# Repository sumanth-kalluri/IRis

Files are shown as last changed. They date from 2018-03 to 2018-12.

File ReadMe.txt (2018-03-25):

Instructions To Run

Dependencies :
tiny_IRremote (For IR Communication on ATtiny85)
IRremote (For IR Communication on Arduino Uno)

The code in "Slave Side" Folder should be burnt to ATtiny85 (with 8Mhz Clock Rate)

The code in "Master Side/IR Interface (Arduino)" Folder should be burnt to Arduino Uno

The folder "Master Side/Hub (Raspberry Pi)" should be copied to Raspberry Pi.

"Master Side/Hub (Raspberry Pi)/Operation Files" contains the python scripts which drive IRis on Raspberry Pi

"Master Side/Hub (Raspberry Pi)/Responses" stores the responses given by students

"Master Side/Hub (Raspberry Pi)/Question Sets" stores the question sets for quizzes

"Master Side/Hub (Raspberry Pi)/Operation Files/serverSync.py" handles the server synchronization and should be added to startup files.

"Master Side/Hub (Raspberry Pi)/IRis-Launcher" invokes the python script in the "Master Side/Hub (Raspberry Pi)/Operation Files" Folder

Hardware Designs can be found in the schematics folder and in the Arduino codes

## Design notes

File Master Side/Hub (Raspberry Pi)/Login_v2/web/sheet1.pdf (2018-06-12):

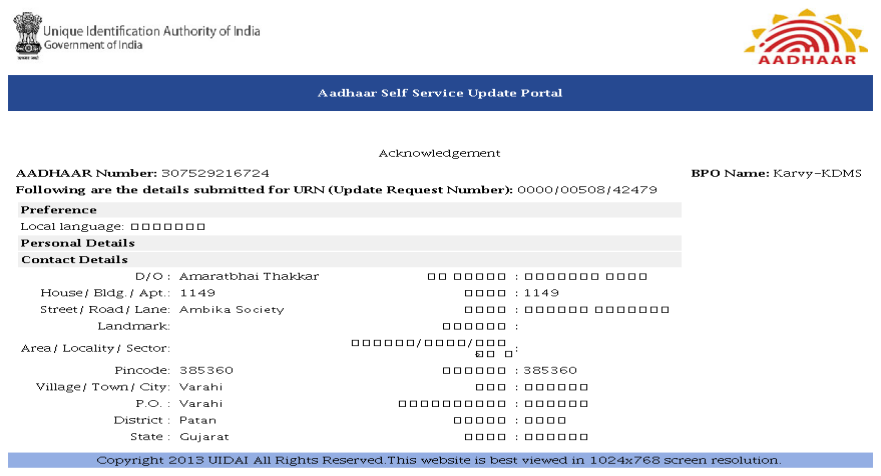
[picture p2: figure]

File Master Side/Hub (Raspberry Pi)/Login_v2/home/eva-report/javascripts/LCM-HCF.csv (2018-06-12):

Roll No. | q1 | ans1 | q2 | ans2 | q3 | ans3 | q4 | ans4 | q5 | ans5 | q6 | ans6 | q7 | ans7 | q8 | ans8 | q9 | ans9 | q10 | ans10 | q11 | ans11 | q12 | ans12 | q13 | ans13 | q14 | ans14 | q15 | ans15
1 | D | 0 | A | MEL420 | C | MEL420 | D | 0 | B | MEL4173 | C | MEL417111 | C | MEL417111 | D | MEL421 | A | 0 | A | 0 | C | MEL420 | B | 0 | A | MEL420 | C | 0 | D | MEL4191
2 | D | 0 | A | MEL420 | C | MEL420 | D | 0 | B | MEL4173 | C | MEL417111 | C | MEL417111 | D | MEL421 | A | 0 | A | 0 | C | MEL420 | B | 0 | A | MEL420 | C | 0 | D | MEL4191
3 | D | 0 | A | MEL420 | C | MEL420 | D | 0 | B | MEL4173 | C | MEL417111 | C | MEL417111 | D | MEL421 | A | 0 | A | 0 | C | MEL420 | B | 0 | A | MEL420 | C | 0 | D | MEL4191
4 | D | 0 | A | MEL420 | C | MEL420 | D | 0 | B | MEL4173 | C | MEL417111 | C | MEL417111 | D | MEL421 | A | 0 | A | 0 | C | MEL420 | B | 0 | A | MEL420 | C | 0 | D | MEL4191
5 | D | 0 | x | x | C | MEL420 | D | 0 | x | x | C | MEL417111 | C | MEL417111 | D | MEL421 | A | 0 | A | 0 | C | MEL420 | B | 0 | x | x | C | 0 | D | MEL4191
6 | D | 0 | A | MEL420 | C | MEL420 | D | 0 | B | MEL4173 | C | MEL417111 | C | MEL417111 | D | MEL421 | A | 0 | A | 0 | C | MEL420 | B | 0 | A | MEL420 | C | 0 | D | MEL4191
7 | D | 0 | A | MEL420 | C | MEL420 | D | 0 | B | MEL4173 | C | MEL417111 | C | MEL417111 | D | MEL421 | A | 0 | A | 0 | C | MEL420 | B | 0 | A | MEL420 | C | 0 | D | MEL4191
8 | D | 0 | A | MEL420 | C | MEL420 | D | 0 | B | MEL4173 | C | MEL417111 | C | MEL417111 | D | MEL421 | A | 0 | A | 0 | C | MEL420 | B | 0 | A | MEL420 | C | 0 | D | MEL4191
9 | D | 0 | A | MEL420 | C | MEL420 | D | 0 | B | MEL4173 | C | MEL417111 | C | MEL417111 | D | MEL421 | A | 0 | A | 0 | C | MEL420 | B | 0 | A | MEL420 | C | 0 | D | MEL4191
10 | D | 0 | A | MEL420 | C | MEL420 | D | 0 | B | MEL4173 | C | MEL417111 | C | MEL417111 | D | MEL421 | A | 0 | A | 0 | C | MEL420 | B | 0 | A | MEL420 | C | 0 | D | MEL4191
11 | D | 0 | A | MEL420 | C | MEL420 | D | 0 | B | MEL4173 | C | MEL417111 | C | MEL417111 | D | MEL421 | A | 0 | A | 0 | C | MEL420 | B | 0 | A | MEL420 | C | 0 | D | MEL4191
12 | D | 0 | A | MEL420 | C | MEL420 | D | 0 | B | MEL4173 | C | MEL417111 | C | MEL417111 | D | MEL421 | A | 0 | A | 0 | C | MEL420 | B | 0 | A | MEL420 | C | 0 | D | MEL4191
13 | D | 0 | A | MEL420 | C | MEL420 | D | 0 | B | MEL4173 | C | MEL417111 | C | MEL417111 | D | MEL421 | A | 0 | A | 0 | C | MEL420 | B | 0 | A | MEL420 | C | 0 | D | MEL4191
14 | D | 0 | A | MEL420 | C | MEL420 | D | 0 | B | MEL4173 | C | MEL417111 | C | MEL417111 | D | MEL421 | A | 0 | A | 0 | C | MEL420 | B | 0 | A | MEL420 | C | 0 | D | MEL4191
15 | D | 0 | A | MEL420 | C | MEL420 | D | 0 | B | MEL4173 | C | MEL417111 | C | MEL417111 | D | MEL421 | A | 0 | A | 0 | C | MEL420 | B | 0 | A | MEL420 | C | 0 | D | MEL4191
16 | D | 0 | A | MEL420 | C | MEL420 | D | 0 | B | MEL4173 | C | MEL417111 | C | MEL417111 | D | MEL421 | A | 0 | A | 0 | C | MEL420 | B | 0 | A | MEL420 | C | 0 | D | MEL4191
17 | D | 0 | A | MEL420 | C | MEL420 | D | 0 | B | MEL4173 | C | MEL417111 | C | MEL417111 | D | MEL421 | A | 0 | A | 0 | C | MEL420 | B | 0 | A | MEL420 | C | 0 | D | MEL4191
18 | D | 0 | A | MEL420 | C | MEL420 | D | 0 | B | MEL4173 | C | MEL417111 | C | MEL417111 | D | MEL421 | A | 0 | A | 0 | C | MEL420 | B | 0 | A | MEL420 | C | 0 | D | MEL4191
19 | D | 0 | A | MEL420 | C | MEL420 | D | 0 | B | MEL4173 | C | MEL417111 | C | MEL417111 | D | MEL421 | A | 0 | A | 0 | C | MEL420 | B | 0 | A | MEL420 | C | 0 | D | MEL4191
20 | D | 0 | A | MEL420 | C | MEL420 | D | 0 | B | MEL4173 | C | MEL417111 | C | MEL417111 | D | MEL421 | A | 0 | A | 0 | C | MEL420 | B | 0 | A | MEL420 | C | 0 | D | MEL4191
21 | D | 0 | A | MEL420 | C | MEL420 | D | 0 | B | MEL4173 | C | MEL417111 | C | MEL417111 | D | MEL421 | A | 0 | A | 0 | C | MEL420 | B | 0 | A | MEL420 | C | 0 | D | MEL4191
22 | D | 0 | A | MEL420 | C | MEL420 | D | 0 | B | MEL4173 | C | MEL417111 | C | MEL417111 | D | MEL421 | A | 0 | A | 0 | C | MEL420 | B | 0 | A | MEL420 | C | 0 | D | MEL4191
23 | D | 0 | A | MEL420 | C | MEL420 | D | 0 | B | MEL4173 | C | MEL417111 | C | MEL417111 | D | MEL421 | A | 0 | A | 0 | C | MEL420 | B | 0 | A | MEL420 | C | 0 | D | MEL4191
24 | D | 0 | A | MEL420 | C | MEL420 | D | 0 | B | MEL4173 | C | MEL417111 | C | MEL417111 | D | MEL421 | A | 0 | A | 0 | C | MEL420 | B | 0 | A | MEL420 | C | 0 | D | MEL4191

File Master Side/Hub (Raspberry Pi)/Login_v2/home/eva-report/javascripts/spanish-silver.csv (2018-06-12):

year | situados_paid | silver_minted | was_american_revolution
1720 | 1226215 | 7874315 | 0
1721 | 1046440 | 9460730 | 0
1722 | 376311 | 8823927 | 0
1723 | 921332 | 8107343 | 0
1724 | 928764 | 7872819 | 0
1725 | 698335 | 7369815 | 0
1726 | 690360 | 8236645 | 0
1727 | 702108 | 8133081 | 0
1728 | 353345 | 9228544 | 0
1729 | 640906 | 8814968 | 0
1730 | 714051 | 9745871 | 0
1731 | 961858 | 8439871 | 0
1732 | 1063585 | 8726466 | 0
1733 | 1148936 | 10009796 | 0
1734 | 308749 | 8506554 | 0
1735 | 1063897 | 7922009 | 0
1736 | 880634 | 11016000 | 0
1737 | 1103957 | 8122133 | 0
1738 | 1083357 | 9490250 | 0
1739 | 524605 | 8550686 | 0
1740 | 1320670 | 9556040 | 0
1741 | 1948375 | 8644177 | 0
1742 | 672024 | 8177000 | 0
1743 | 1622300 | 8619000 | 0
1744 | 1349189 | 10285000 | 0
1745 | 1493178 | 10327500 | 0
1746 | 1457684 | 11509000 | 0
1747 | 1468279 | 12002000 | 0
1748 | 2402106 | 11628000 | 0
1749 | 2138665 | 11823500 | 0
1750 | 1614920 | 13209000 | 0
1751 | 848271 | 12631000 | 0
1752 | 918960 | 13625500 | 0
1753 | 2227312 | 11594000 | 0
1754 | 1775134 | 11594000 | 0
1755 | 2064520 | 12486500 | 0
1756 | 311502 | 12299500 | 0
1757 | 3687895 | 12529000 | 0
1758 | 2313552 | 12757591 | 0
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

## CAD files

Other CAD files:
Casing/IRis Slave Casing (AA Cell - Bottom Loading).dwg
Casing/IRis Slave Casing (CR2032 Cell).dwg
Casing/IRis Slave Casing (AA Cell - Side Loading).dwg

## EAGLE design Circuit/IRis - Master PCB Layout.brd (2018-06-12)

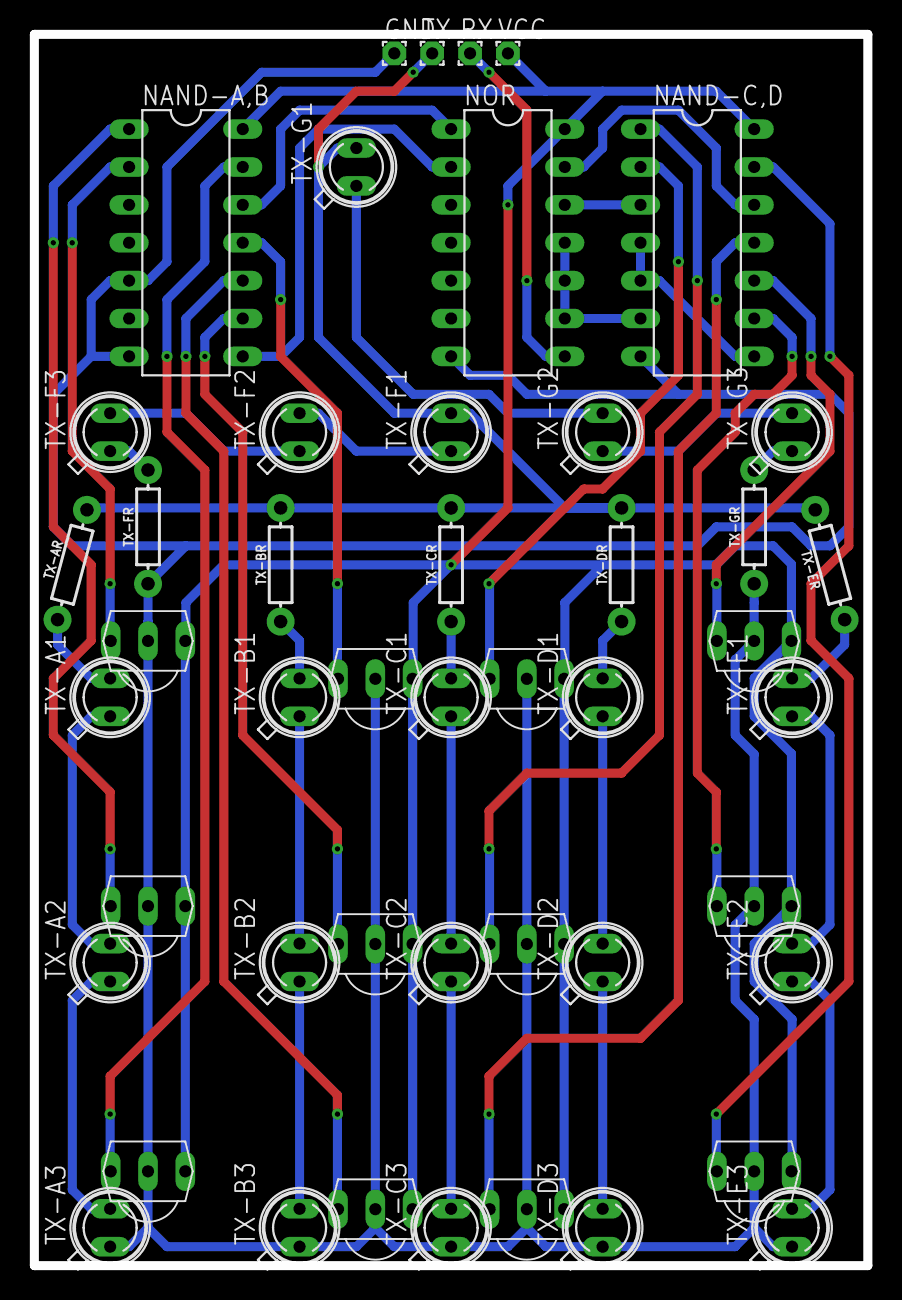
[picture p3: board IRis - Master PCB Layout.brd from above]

Board: 2 copper layers, 55.9 x 82.5 mm, 47 parts (0 on the bottom side), 43 nets.

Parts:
GND: GND; 1,6/0,8
NAND-A,B: 7410; DIL14
NAND-C,D: 7410; DIL14
NOR: 7427; DIL14
RX: RX; 1,6/0,8
RX-A1, RX-A2, RX-A3: VS1838B; TSOP18XX
RX-B1, RX-B2, RX-B3: VS1838B; TSOP18XX
RX-C1, RX-C2, RX-C3: VS1838B; TSOP18XX
RX-D1, RX-D2, RX-D3: TSOP18XX
TX: TX; 1,6/0,8
TX-A1: IR LED; SFH480
TX-A2, TX-A3: SFH480
TX-AR: AXIAL-0.3EZ
TX-B1, TX-B2, TX-B3: SFH480
TX-BR: AXIAL-0.3EZ
TX-C1, TX-C2, TX-C3: SFH480
TX-CR: AXIAL-0.3EZ
TX-D1, TX-D2, TX-D3: SFH480
TX-DR: AXIAL-0.3EZ
TX-E1, TX-E2, TX-E3: SFH480
TX-ER: AXIAL-0.3EZ
TX-F1, TX-F2, TX-F3: SFH480
TX-FR: AXIAL-0.3EZ
TX-G1, TX-G2, TX-G3: SFH480
TX-GR: AXIAL-0.3EZ
VCC: VCC; 1,6/0,8

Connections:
GND: GND.1, NAND-A,B.5, NAND-A,B.7, NAND-C,D.7, NOR.7, RX-A1.GND, RX-A2.GND, RX-A3.GND, RX-B1.GND, RX-B2.GND, RX-B3.GND, RX-C1.GND, RX-C2.GND, RX-C3.GND, RX-D1.GND, RX-D2.GND, RX-D3.GND, TX-A3.K, TX-B3.K, TX-C3.K, TX-D3.K, TX-E3.K, TX-FR.P$1, TX-GR.P$1
RX: NOR.8, RX.1
S$23: NAND-C,D.4, NAND-C,D.5, NAND-C,D.8
S$25: NAND-C,D.1, RX-C2.OUT
S$26: NAND-C,D.11, RX-C3.OUT
S$27: NAND-C,D.9, RX-D2.OUT
S$29: NAND-C,D.2, RX-C1.OUT
S$32: NAND-C,D.12, NOR.13
S$33: NAND-C,D.3, NOR.12
S$34: NAND-C,D.6, NOR.9, NOR.10, NOR.11
S$35: NAND-A,B.12, NOR.1
S$36: NAND-A,B.8, NOR.2
S$37: NAND-A,B.2, RX-A1.OUT
S$38: NAND-A,B.1, RX-A2.OUT
S$39: NAND-A,B.13, RX-A3.OUT
S$40: NAND-A,B.11, RX-B1.OUT
S$41: NAND-A,B.9, RX-B2.OUT
S$42: NAND-A,B.10, RX-B3.OUT
S$43: NAND-C,D.10, RX-D1.OUT
S$44: NAND-C,D.13, RX-D3.OUT
TX: TX.1, TX-AR.P$2, TX-BR.P$2, TX-CR.P$2, TX-DR.P$2, TX-ER.P$2, TX-F1.A, TX-G1.A
TX-A1,A2: TX-A1.K, TX-A2.A
TX-A2,A3: TX-A2.K, TX-A3.A
TX-AR,A1: TX-A1.A, TX-AR.P$1
TX-B1,B2: TX-B1.K, TX-B2.A
TX-B2,B3: TX-B2.K, TX-B3.A
TX-BR,B1: TX-B1.A, TX-BR.P$1
TX-C1,C2: TX-C1.K, TX-C2.A
TX-C2,C3: TX-C2.K, TX-C3.A
TX-CR,C1: TX-C1.A, TX-CR.P$1
TX-D1,D2: TX-D1.K, TX-D2.A
TX-D2,D3: TX-D2.K, TX-D3.A
TX-DR,D1: TX-D1.A, TX-DR.P$1
TX-E1,E2: TX-E1.K, TX-E2.A
TX-E2,E3: TX-E2.K, TX-E3.A
TX-ER,E1: TX-E1.A, TX-ER.P$1
TX-F1,F2: TX-F1.K, TX-F2.A
TX-F2,F3: TX-F2.K, TX-F3.A
TX-F3,FR: TX-F3.K, TX-FR.P$2
TX-G1,G2: TX-G1.K, TX-G2.A
TX-G2,G3: TX-G2.K, TX-G3.A
TX-G3,R: TX-G3.K, TX-GR.P$2
VCC: NAND-A,B.14, NAND-C,D.14, NOR.14, RX-A1.VCC, RX-A2.VCC, RX-A3.VCC, RX-B1.VCC, RX-B2.VCC, RX-B3.VCC, RX-C1.VCC, RX-C2.VCC, RX-C3.VCC, RX-D1.VCC, RX-D2.VCC, RX-D3.VCC, VCC.1

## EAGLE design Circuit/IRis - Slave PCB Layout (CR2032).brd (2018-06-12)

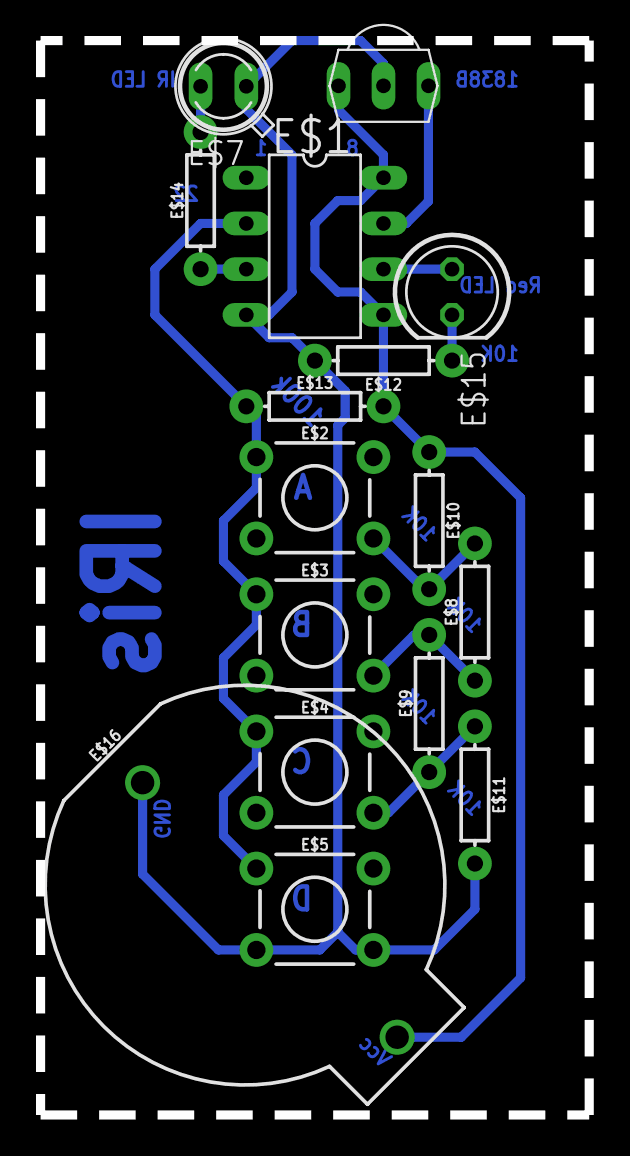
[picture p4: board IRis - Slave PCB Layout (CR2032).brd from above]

Board: 2 copper layers, 30.5 x 59.7 mm, 16 parts (0 on the bottom side), 11 nets.

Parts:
E$1: DIL8
E$2, E$3, E$4, E$5: TACTILE_SWITCH_PTH_6.0MM
E$6: TSOP18XX
E$7: SFH480
E$8, E$9, E$10, E$11, E$12, E$13, E$14: AXIAL-0.3
E$15: LED5MM
E$16: BATTCOM_20MM_PTH

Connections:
GND: E$1.4, E$5.3, E$5.4, E$6.GND, E$7.K, E$11.P$2, E$12.P$2, E$16.2
S$1: E$2.4, E$8.P$2, E$10.P$2
S$2: E$1.5, E$1.8, E$6.VCC, E$10.P$1, E$13.P$2, E$16.1
S$3: E$3.4, E$8.P$1, E$9.P$2
S$4: E$1.3, E$14.P$1
S$5: E$1.2, E$2.1, E$3.1, E$4.1, E$5.1, E$13.P$1
S$6: E$4.4, E$9.P$1, E$11.P$1
S$7: E$7.A, E$14.P$2
S$8: E$1.7, E$6.OUT
S$9: E$1.6, E$15.A
S$10: E$12.P$1, E$15.K

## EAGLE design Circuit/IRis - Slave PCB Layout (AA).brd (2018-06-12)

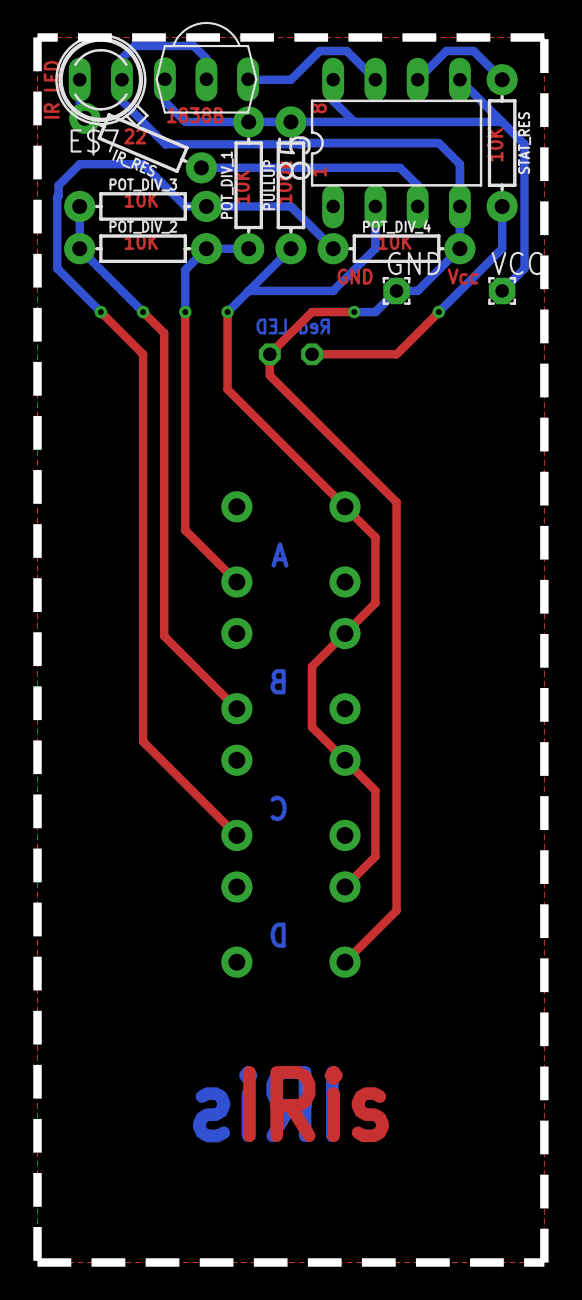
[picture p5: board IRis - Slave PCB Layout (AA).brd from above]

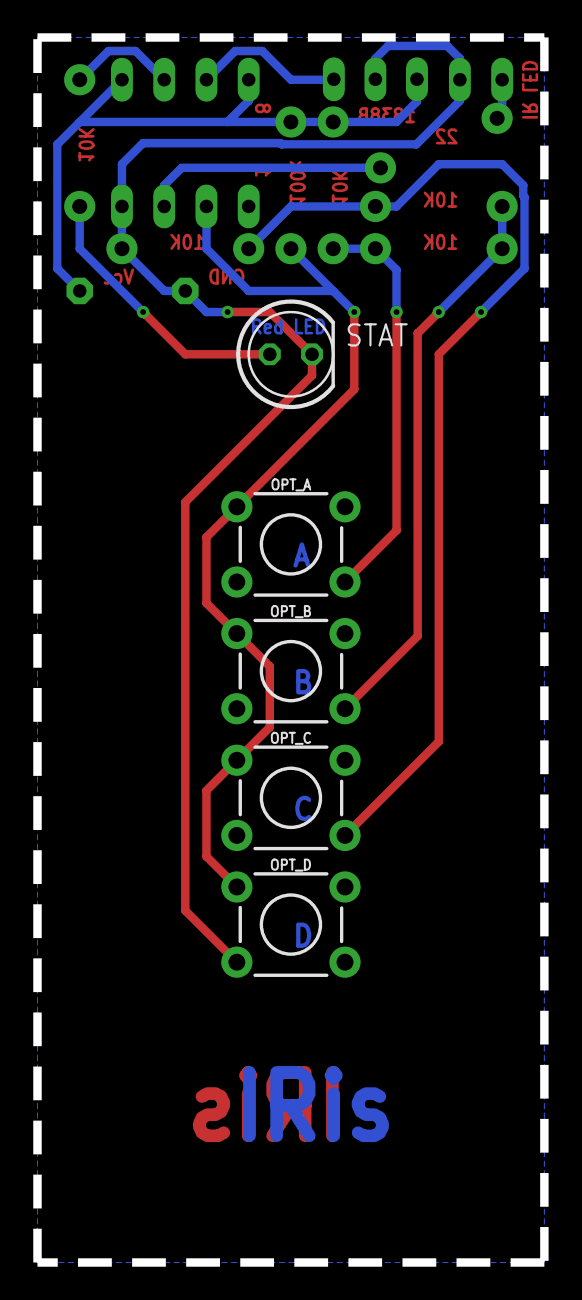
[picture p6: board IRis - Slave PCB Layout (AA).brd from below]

Board: 2 copper layers, 30.5 x 73.7 mm, 17 parts (5 on the bottom side), 11 nets.

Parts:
85: DIL8
E$6: TSOP18XX
E$7: SFH480
GND: 1,6/0,8
IR_RES: 22; AXIAL-0.3
OPT_A: TACTILE_SWITCH_PTH_6.0MM
OPT_B: TACTILE_SWITCH_PTH_6.0MM
OPT_C: TACTILE_SWITCH_PTH_6.0MM
OPT_D: TACTILE_SWITCH_PTH_6.0MM
POT_DIV_1, POT_DIV_2, POT_DIV_3, POT_DIV_4: 10k; AXIAL-0.3
PULLUP: 100k; AXIAL-0.3
STAT: LED5MM
STAT_RES: 10k; AXIAL-0.3
VCC: 1,6/0,8

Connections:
GND: 85.4, E$6.GND, E$7.K, GND.1, OPT_D.3, POT_DIV_4.P$2, STAT.K
OPT_IP: 85.2, OPT_A.1, OPT_B.1, OPT_C.1, OPT_D.1, PULLUP.P$1
S$1: OPT_A.4, POT_DIV_1.P$1, POT_DIV_2.P$2
S$2: 85.7, E$6.OUT
S$3: 85.6, STAT_RES.P$1
S$4: E$7.A, IR_RES.P$2
S$5: STAT.A, STAT_RES.P$2
S$7: 85.3, IR_RES.P$1
S$12: OPT_C.4, POT_DIV_3.P$2, POT_DIV_4.P$1
S$13: OPT_B.4, POT_DIV_2.P$1, POT_DIV_3.P$1
VCC: 85.5, 85.8, E$6.VCC, POT_DIV_1.P$2, PULLUP.P$2, VCC.1

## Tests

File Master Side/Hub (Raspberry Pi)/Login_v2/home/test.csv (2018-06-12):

SL NO | QUESTION | OPTION A | ERROR CODE A | OPTION B | ERROR CODE B | OPTION C | ERROR CODE C | OPTION D | ERROR CODE D | Time (in minutes)
1 | There are 5 birds living near the mountain. If 4 birds flew away for winter. How many birds were left near the mountain? | 9 | ME3081 | 1 | null | 20 | ME3081 | 54 | ME2081 | 3
2 | There are 8 birds living near the mountain. If 8 birds flew away for winter. How many birds were left near the mountain? | 16 | ME3081 | 64 | ME3081 | 2 | ME306 | 0 | null | 3
3 | There are 20 birds living near the mountain. If 12 birds flew away for winter. How many birds were left near the mountain? | 32 | ME3081 | 8 | null | 9 | ME306 | 240 | ME3081 | 3
4 | There are 17 birds living near the mountain. If 9 birds flew away for winter. How many birds were left near the mountain? | 8 | Null | 26 | ME3081 | 153 | ME3081 | 179 | ME2081 | 3
5 | There are 4 birds living near the mountain. If 4 birds flew away for winter. How many birds were left near the mountain? | 8 | ME3081 | 0 | null | 16 | ME3081 | 1 | ME306 | 3
6 | There are 12 birds living near the mountain. If 8 birds flew away for winter. How many birds were left near the mountain? | 20 | ME3081 | 96 | ME3081 | 6 | ME306 | 4 | null | 3
7 | There are 45 birds living near the mountain. If 39 birds flew away for winter. How many birds were left near the mountain? | 16 | ME3062 | 6 | null | 84 | ME3081 | 8 | ME306 | 3
8 | There are 37 birds living near the mountain. If 28 birds flew away for winter. How many birds were left near the mountain? | 19 | ME3062 | 9 | null | 65 | ME3081 | 8 | ME306 | 3
9 | There are 22 birds living near the mountain. If 16 birds flew away for winter. How many birds were left near the mountain? | 152 | ME3081 | 38 | ME3081 | 16 | ME3062 | 6 | Null | 3
10 | There are 81 birds living near the mountain. If 79 birds flew away for winter. How many birds were left near the mountain? | 160 | ME3081 | 3 | ME306 | 12 | ME3062 | 2 | null | 3
11 | There are 43 birds living near the mountain. If 25 birds flew away for winter. How many birds were left near the mountain? | 68 | ME3081 | 18 | Null | 28 | ME3062 | 4325 | ME2081 | 3
12 | There are 80 birds living near the mountain. If 9 birds flew away for winter. How many birds were left near the mountain? | 71 | Null | 720 | ME3081 | 89 | ME3081 | 81 | ME3062 | 3
13 | What comes after Thursday? | Wednesday | ME3115 | Friday | Null | Saturday | ME3116 | January | ME3110 | 3
14 | What comes before Wednesday? | Thursday | ME3115 | Tuesday | Null | March | ME3110 | Sunday | ME3116 | 3
15 | What comes before Saturday? | Sunday | ME3115 | Monday | ME3116 | Sunday | Null | September | ME3110 | 3
16 | What comes after Monday? | Sunday | ME3115 | Tuesday | Null | Wednesday | ME3116 | Morning | ME3110 | 3
17 | How many days are there in a week? | 7 | Null | 12 | ME3110 | 24 | ME3110 | 100 | ME311A | 3
18 | How many days are in January? | 30 | ME3116 | 1 | ME3115 | 45 | ME311 | 31 | Null | 3
19 | How many days are in November? | 30 | Null | 31 | ME3116 | 11 | ME3115 | 2 | ME311 | 3
20 | Which month is spoken off in 4/10/1956? | April | ME3110 | January | ME2063 | October | Null | July | ME3111 | 3
21 | Which month is spoken off in 2/9/12? | February | ME3110 | 12 | ME3110 | September | Null | October | ME3111 | 3
22 | Which month is spoken off in 15/6/1787? | June | Null | Saturday | ME3110 | August | ME3111 | Rain | ME311 | 3
23 | Shiela was born in 1980. What is her age in 2011? | 21 | Null | 12 | ME2063 | 69 | ME3112 | 2011 | ME3115 | 3
24 | Manu was born in 2010. What is her age in 2013? | 3 | Null | 30 | ME2063 | 23 | ME3112 | 2011 | ME3115 | 3
25 | Rasiya was 19 years old in 2011. When was she born? | 192 | ME3112 | 1992 | Null | 2030 | ME3115 | 1986 | ME3112 | 3
26 | Kalu was 62 years old in 1956. When was he born? | 1896 | Null | 1890 | ME116 | 2018 | ME3112 | 1930 | ME2063 | 3
27 | When a year is called leap year? | February has 29 days | Null | March has 29 days | ME3113 | February has 28 days | ME3115 | August has 31 days | ME3115 | 3
28 | If 2012 was leap year then when is the next leap year? | 2016 | Null | 2017 | ME2116 | 2008 | ME3115 | 2013 | ME3113 | 3

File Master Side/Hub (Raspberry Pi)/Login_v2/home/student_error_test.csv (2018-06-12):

sid | e1 | e2 | e3 | e4
1 | 0 | 4 | 2 | 5
2 | 6 | 2 | 4 | 2
3 | 2 | -1 | 4 | 3

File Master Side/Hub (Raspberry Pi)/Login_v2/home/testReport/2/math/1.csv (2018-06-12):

sid | q1 | q2 | q3 | q4
1 | 3 | 4 | 2 | 5
2 | 6 | 2 | 4 | 2
3 | 2 | -1 | 4 | 3

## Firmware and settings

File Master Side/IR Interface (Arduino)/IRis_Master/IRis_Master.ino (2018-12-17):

 /*
 * Project          : IRis
 * Purpose          : HackFest 2018 - The Annual 36 Hour Hackathon At IIT (ISM) Dhanbad
 * Module           : Master IR Interface (Arduino)
 ---------------------------------------------------------------------------------------
 * Board            : Arduino Uno R3
 * IR Demodulator   : VS1838B
 * Library          : IRremote (For IR Communication with Arduino Series) [https://github.com/z3t0/Arduino-IRremote]
 * IDE              : Arduino IDE 1.8.4 On Ubuntu 16.04 LTS
 ---------------------------------------------------------------------------------------
 * Author           : Nishad Mandlik, Sumanth, Ruthvik
 * Organization     : RoboISM - The Robotics Club Of IIT (ISM) Dhanbad
 * 
*/

//Digital Pin 3   : IR Tx
//Digital Pin 2  : IR Rx

#include <IRremote.h>
#define UID 0

#define STOP_CODE 0
#define INIT_CODE 1
#define ENQUIRE_CODE 2
#define RESET_CODE 3

uint16_t usrIp = 0;

//Array To Store Bitwise Availability Status Of All Slaves.
uint8_t slaveAvail[8] = {0,0,0,0,0,0,0,0};

uint16_t irOut[] = {5000, 2500, 750, 750, 750, 750, 750, 750, 750, 750, 750, 750, 750, 750, 750, 750, 750, 750, 500};
byte decodeStat = 1;

//Array To Store The UIDs Of Slaves Which Are Available.
//0th Element Stores Number Of Such Active Slaves
uint8_t UIDActive[64];


IRsend irtx; //Library Object to Send IR Signals.
IRrecv irrx(2); //Library Objet to Receive IR Signals.

decode_results irIn;

//Structure To Store Data Decoded From The IR Signal.
struct irCmd {
  //According To The IR Protocol Used, Information Is Received Bytewise.
  //The 6 MSBs Contain Address Of Transmitting Slave.
  //The 2 LSBs Denote User-Input Of Slave.
  uint8_t address: 6;
  uint8_t option: 2;
}irResponse;

//Function To Convert IR Signal To Byte Data
uint8_t decodeRaw() {
  //Signal Is Present In Ticks Of 50uS.
  /*for(int i = 0; i < 20; i++)
  {
    Serial.println(irIn.rawbuf[i]);
  }*/
  //First HIGH Pulse : 5000 (3500 to 6500)
  if (irIn.rawbuf[1]<70 && irIn.rawbuf[1]>130) {
    return 1;
  }
  
  //First LOW Pulse : 2500 (1500 to 3500)
  if (irIn.rawbuf[2]<30 && irIn.rawbuf[2]>70) {
    return 2;
  }

  //End HIGH Pulse : 500 (250 To 750)
  if (irIn.rawbuf[19]<5 && irIn.rawbuf[19]>15) {
    return 3;
  }

  //First 6 bits (Address)
  for (uint8_t i=3; i<15; i+=2) {
    irResponse.address = irResponse.address<<1;
    if (irIn.rawbuf[i]>irIn.rawbuf[i+1]) {
      //HIGH Pulse
      irResponse.address = irResponse.address | 0b00000001;
    }
    else if (irIn.rawbuf[i]<=irIn.rawbuf[i+1]) {
      //LOW Pulse
      irResponse.address = irResponse.address & 0b11111110;
    }
    else {
      return 4;
    }
  }

  //Last 2 bits (Instruction)
  for (uint8_t i=15; i<19; i+=2) {      
    irResponse.option = irResponse.option<<1;
    if (irIn.rawbuf[i]>irIn.rawbuf[i+1]) {
      //HIGH Pulse :
      //Serial.println("HIGH");
      irResponse.option = irResponse.option | 0b00000001;
    }
    else if (irIn.rawbuf[i]<=irIn.rawbuf[i+1]) {
      //LOW Pulse : 
      //Serial.println("LOW");
      irResponse.option = irResponse.option & 0b11111110;
    }
    else {
      return 5;
    }
  }
  return 0;
}

//Encode A Byte Of Data Into Pulse Width Modulated Form
void encodeRaw(uint8_t adr, uint8_t opt) {
  for (byte i = 6; i>=1; i--)
  {
    if ((adr>>(6-i)) & 0b1) {
      //When bit is 1
      irOut[2*i] = 1000;      //HIGH Time (in uS)
      irOut[2*i + 1] = 500;   //LOW Time (in uS)
    }
    else {
      //When bit is 0
      irOut[2*i] = 500;       //HIGH Time (in uS)
      irOut[2*i + 1] = 1000;  //LOW Time (in uS)
    } 
  }
  for (byte i = 2; i>=1; i--)
  {
    if ((opt>>(2-i)) & 0b1) {
      //When bit is 1
      irOut[2*i + 12] = 1000; //HIGH Time (in uS)
      irOut[2*i + 13] = 500;  //LOW Time (in uS)
    }
    else {
      //When bit is 0
      irOut[2*i + 12] = 500;  //HIGH Time (in uS)
      irOut[2*i + 13] = 1000; //LOW Time (in uS)
    } 
  }
  return;
}

uint8_t slaveResponse(uint8_t slaveID, uint8_t slaveOp) {
  //If Slave Responds Properly, This Function Will Return 1 or 2, Else It Will Return 0.
  encodeRaw(slaveID,slaveOp);
  uint8_t temp=0;    
  irtx.sendRaw(irOut, sizeof(irOut) / sizeof(irOut[0]), 38);
  irrx.enableIRIn();
  while (!irrx.decode(&irIn)) {
    temp+=1;
    delay(1);
    if (temp > 50) {
      return 0;
    }
  }  
  decodeStat = decodeRaw();
  if (irResponse.address == slaveID) {
    //For Options A, B, C, D
    if (decodeStat == 0) {
      return 1;
    }

    //For No Option Entered
    else if (decodeStat == 5) {
      return 2;        
    }
  }
}

uint8_t initSlaves(uint8_t ID) {
  //If ID Is Non-Zero, Only The Slave Corresponding To That ID Will Be Initialized.
  //If ID is Zero, All Slaves Will Be Initialized.

  //After Initialization, Availability Status Of All (63) Slaves Will Be Updated In "slaveAvail" Array.
  //LSB Of 0th Element of "slaveAvail" Is Reserved For Master.
  //The Rest 63 Bits (7 Bits Of 0th Element & 8 Bits Each Of All Other Elements) Store The Availability Status Of 63 Slaves.

  Serial.print('*');
  Serial.print(INIT_CODE);
  Serial.print(':');
  
  if (ID) {
    //Transmit The Status To The Serial Host.
    Serial.print(ID);
    Serial.print('/');
    if (slaveResponse(ID,1)) {
      Serial.println("T#");
      return 1;
    }
    Serial.println("F#");
    return 2;
  }

  //Initially Set The Number Of Active Slaves To Zero.
  UIDActive[0] = 0;
  
  //For 0th Device (Master)
  slaveAvail[0] = 0b10000000;

  //For All Slaves
  for (uint8_t i = 1; i<64; i++) {
    //Insert Availability Status From MSB And Shift If Leftwards One By One.
    slaveAvail[i/8] = slaveAvail[i/8]>>1;
    if (slaveResponse(i,1)) {
      slaveAvail[i/8] = slaveAvail[i/8] | 0b10000000; //Make The MSB = 1, And Keep Rest Bits Unchanged.
      UIDActive[0] = UIDActive[0] + 1; //Increase The Number Of Active Slaves By 1.
      UIDActive[UIDActive[0]] = i; //Append The Slave UID To The List Of Active Slave.
    }
  }

  //Transmit The Status To The Serial Host
  for (uint8_t i = 0; i<7; i++) {
    Serial.print((char)slaveAvail[i]);
    Serial.print(',');
  }
  Serial.print((char)slaveAvail[7]);
  Serial.println('#');
  return 0;
}

uint8_t askSlaves(uint8_t ID) {
  Serial.print('*');
  Serial.print(ENQUIRE_CODE);
  Serial.print(':');
  
  //If ID Is Non-Zero, Only The Slave Corresponding To That ID Will Be Enquired.
  //If ID is Zero, All Slaves Will Be Enquired.
  if (ID) {
    //Transmit The Inputs Recorded By Slave To The Serial Host
    if (slaveResponse(ID,2)) {
      Serial.print(ID);
      Serial.print('/');
      Serial.print(irResponse.option);
      Serial.println('#');
      return 1;
    }
  }

  //Array To Store Options Recorded By Available Slaves.
  uint8_t slaveOpts[UIDActive[0]+1];

  //Run The Loop For All Active Slaves
  for (uint8_t i = 1; i<=UIDActive[0]; i++) {
    uint8_t resp = slaveResponse(UIDActive[i],2);
    if (resp==1) {
      //Convert 0-3 To 65-68 (ASCII Values Of A-D)
      slaveOpts[i] = irResponse.option + 65;
    }
    else if (resp==2) {
      slaveOpts[i] = 78;
    }
  }

  //Transmit The Inputs Recorded By Slaves To The Serial Host.
  for (uint8_t i = 1; i<UIDActive[0]; i++) {
    Serial.print(UIDActive[i]);
    Serial.print('/');
    Serial.print((char)slaveOpts[i]);
    Serial.print(',');
  }
  Serial.print(UIDActive[UIDActive[0]]);
  Serial.print('/');
  Serial.print((char)slaveOpts[UIDActive[0]]);
  Serial.println('#'); 
}

void setup() {
  Serial.begin(115200);
  //Serial.println("Start");
  encodeRaw(UID,2);
  irrx.enableIRIn();
  //Serial.println("Enabled\n");
}

void loop() {
  //Send The Encoded Signal
  if (!Serial.available()) {
    return;
  }
  if (Serial.read()!='*') {
    return;
  }
  uint8_t opCode = Serial.parseInt();
  uint8_t arg = Serial.parseInt();
  if (opCode == 0 || opCode == 3) {
    encodeRaw(arg,opCode);  
    irtx.sendRaw(irOut, sizeof(irOut) / sizeof(irOut[0]), 38);
    irrx.enableIRIn();
  }
  else if (opCode == 1) {
    initSlaves(arg);
  }
  else if (opCode == 2) {
    askSlaves(arg);
  }
  else {
    Serial.print('*');
    Serial.print(opCode);
    Serial.println(":Z#");
  }
  irrx.resume();
}

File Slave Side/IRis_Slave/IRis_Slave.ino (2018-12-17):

/*
 * Project          : IRis
 * Purpose          : HackFest 2018 - The Annual 36 Hour Hackathon At IIT (ISM) Dhanbad
 * Module           : Slave (Remote)
 ---------------------------------------------------------------------------------------
 * Microcontroller  : ATtiny85
 * IR Demodulator   : VS1838B
 * Programmer       : Arduino Uno R3 as ISP
 * Library          : tiny_IRremote (For IR Communication on ATtiny Series)
 * IDE              : Arduino IDE 1.8.4 On Ubuntu 16.04 LTS
 ---------------------------------------------------------------------------------------
 * Author           : Sumanth
 * Organization     : RoboISM - The Robotics Club Of IIT (ISM) Dhanbad
 * 
 */


//  Pin 1 (Reset)         : Unused
//  Pin 2 (GPIO-3/ANLG-3) : User-Input
//  Pin 3 (GPIO-4/ANLG-2) : IR Tx
//  Pin 4                 : GND
//  Pin 5 (GPIO-0/AREF)   : GND
//  Pin 6 (GPIO-1)        : Red LED
//  Pin 7 (GPIO-2/ANLG-1) : IR Rx
//  Pin 8                 : +Vcc

#include <tiny_IRremote.h>
#define UID 21
#define LED_RED 1
#define OPT_IP A3

uint16_t usrIp = 0;
unsigned int irOut[] = {5000, 2500, 750, 750, 750, 750, 750, 750, 750, 750, 750, 750, 750, 750, 750, 750, 750, 750, 500};

struct irCmd {
  byte address: 6;
  byte opcode: 2;
}irQuery;

IRsend irtx; //Library Object to Send IR Signals
IRrecv irrx(2); //Library Objet to Receive IR Signals

decode_results irIn;

uint8_t decodeRaw() {
  //Signal Is Present In Ticks Of 50uS.

  //First HIGH Pulse : 5000 (3500 to 6500)
  if (irIn.rawbuf[1]<70 && irIn.rawbuf[1]>130) {
    return 1;
  }
  
  //First LOW Pulse : 2500 (1500 to 3500)
  if (irIn.rawbuf[2]<30 && irIn.rawbuf[2]>70) {
    return 2;
  }

  //End HIGH Pulse : 500 (250 To 750)
  if (irIn.rawbuf[19]<5 && irIn.rawbuf[19]>15) {
    return 3;
  }

  //First 6 bits (Address)
  for (uint8_t i=3; i<15; i+=2) {    
    irQuery.address = irQuery.address<<1;
    if (irIn.rawbuf[i]>irIn.rawbuf[i+1]) {
      //High
      irQuery.address = irQuery.address | 0b00000001;
    }
    else if (irIn.rawbuf[i]<irIn.rawbuf[i+1]) {
      //Low
      irQuery.address = irQuery.address & 0b11111110;
    }
    else {
      return 4;
    }
  }

  //Last 2 bits (Instruction)
  for (uint8_t i=15; i<19; i+=2) {      
    irQuery.opcode = irQuery.opcode<<1;
    if (irIn.rawbuf[i]>irIn.rawbuf[i+1]) {
      //High
      irQuery.opcode = irQuery.opcode | 0b00000001;
    }
    else if (irIn.rawbuf[i]<irIn.rawbuf[i+1]) {
      //Low
      irQuery.opcode = irQuery.opcode & 0b11111110;
    }
    else {
      return 5;
    }
  }
  return 0;
}


void setup() {
  ADMUX = ADMUX & 0b00111111; //Set REFS1=0 And REFS0=0 To Set Analog Reference (AREF) To Vcc.
  
  /*

  better to create new code. keep this one for old devices
  Analog user input pulled up.
  comparator negative = 2.56 or vcc from pin 5
  adc value left align and read only upper byte. forget two lsbs
  
   
  MCUCR = MCUCR | 0b00100000; //Set The SE (Sleep Enable) Bit in MCUCR

  //Select Sleep Mode As IDLE
  //Set SM1 Bit, Reset SM0 Bit
  MCUCR = MCUCR | 0b00010000;
  MCUCR = MCUCR & 0b11110111;

  //Turn Off USI, Timer0 & ADC
  PRR = PRR | 0b00000111;

  //Set PCIE (PinChange Interrupt Enable) Bit in GIMSK (General Interrupt Mask Registered)
  GIMSK = GIMSK | 0b00100000;

  //Enable PinChange Interrupt For GPIO 


  sreg interrupt enable
GIMSK enable pin change (PCIE)
enable pin change interrupt on selected pins in pcmsk
  
   */
  for (uint8_t i = 6; i>=1; i--)
  {
    if ((UID>>(6-i)) & 0b1) {
      //When bit is 1
      irOut[2*i] = 1000;
      irOut[2*i + 1] = 500;
    }
    else {
      //When bit is 0
      irOut[2*i] = 500;
      irOut[2*i + 1] = 1000;
    } 
  }
  pinMode(LED_RED, OUTPUT);
  pinMode(OPT_IP, INPUT);
  irrx.enableIRIn(); // Start the receiver
  digitalWrite(LED_RED, HIGH);
  delay(50);
  digitalWrite(LED_RED, LOW);
}

void loop() {
  //MSB Of usrIp Is Used As Input Acceptance Flag.
  //If It Is RESET, New Inputs Would Be Taken And irOut Data Will Be Changed Accordingly.
  //If It Is SET, New Inputs Would Be Taken But The Change Would Not Be Reflected In "irOut".
  usrIp = (usrIp & 0x8000) | analogRead(OPT_IP);

  //When MSB Of usrIp Is 1, None Of The Following Conditions Are Satisfied.
  //So, No Changes Are Made To "irOut".
  if (usrIp<128) {
    //~0 - Option D  [11]    
    irOut[14] = 1000;
    irOut[15] = 500;
    irOut[16] = 1000;
    irOut[17] = 500;
    digitalWrite(LED_RED, HIGH);
    delay(50);
    digitalWrite(LED_RED, LOW);
  }
  else if (usrIp>128 && usrIp<384) {
    //~256 - Option C [10]
    irOut[14] = 1000;
    irOut[15] = 500;
    irOut[16] = 500;
    irOut[17] = 1000;
    digitalWrite(LED_RED, HIGH);
    delay(50);
    digitalWrite(LED_RED, LOW);
  }
  else if (usrIp>384 && usrIp<640) {
    //~512 - Option B [01]
    irOut[14] = 500;
    irOut[15] = 1000;
    irOut[16] = 1000;
    irOut[17] = 500;
    digitalWrite(LED_RED, HIGH);
    delay(50);
    digitalWrite(LED_RED, LOW);
  }
  else if (usrIp>640 && usrIp<896) {
    //~768 - Option A [00]
    irOut[14] = 500;
    irOut[15] = 1000;
    irOut[16] = 500;
    irOut[17] = 1000;
    digitalWrite(LED_RED, HIGH);
    delay(50);
    digitalWrite(LED_RED, LOW);
  }
  
  if (!(irrx.decode(&irIn))) {
    return;
  }

  if (!decodeRaw()) {
    if (irQuery.opcode == 0b00 && (irQuery.address == 0 || irQuery.address == UID)) {
      //OpCode 00 : Stop Input
      usrIp = usrIp | 0x8000;
      digitalWrite(LED_RED, HIGH);
    }
    else if ((irQuery.opcode == 0b01 || irQuery.opcode == 0b10) && irQuery.address == UID) {
      //OpCode 01 : Ping
      //OpCode 10 : Send Input
      
      //Send The Encoded Signal
      irtx.sendRaw(irOut, sizeof(irOut) / sizeof(irOut[0]), 38);
      
      //Re-Enable The Receiver
      irrx.enableIRIn();
      
      //Start Accepting User-Input
      usrIp = 0;
      
      //Reset The Data Part Of "irOut" To Blank Response (No Button Pressed)
      irOut[14] = 750;
      irOut[15] = 750;
      irOut[16] = 750;
      irOut[17] = 750;
      digitalWrite(LED_RED, LOW);
    }
    else if (irQuery.opcode == 0b11 && (irQuery.address == 0 || irQuery.address == UID)) {
      //OpCode 11 : Reset Input

      //Reset The Data Part Of "irOut" To Blank Response (No Button Pressed)
      irOut[14] = 750;
      irOut[15] = 750;
      irOut[16] = 750;
      irOut[17] = 750;
      digitalWrite(LED_RED, LOW);
    }
  }
  
  //Accept Next IR Data
  irrx.resume();   
    
}

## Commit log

2018-03-24 Working Version
    [IRis - Slave Schematic.sch, India.csv]
2018-03-25 Documantation Added
    [IRis - Slave Schematic.sch]
2018-05-10 PCB Layout Added
    [IRis - Slave PCB Layout.brd, IRis - Slave PCB Layout.dxf, IRis - Slave Schematic.sch]
2018-06-12 PCB Layout Included For AA Cell and CR2032 Cell. Gerber Files Added
    [IRis - Master PCB Layout.brd, IRis - Slave PCB Layout (AA).brd, IRis - Slave PCB Layout (CR2032).brd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]
2018-06-12 Deprecated Files Removed
    [IRis - Slave PCB Layout.dxf]
2018-06-12 Web Interface Integrated
    [1-BAK.csv, 1.csv, 2.csv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]
2018-06-13 Test Analysis (Beta) Included
    [1.csv]
2018-06-13 Web Interface Updated
    [1-BAK.csv, 1.csv, 2.csv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]
2018-06-16 CAD Files For Casing Added
    [IRis Slave Casing (AA Cell - Side Loading).dwg, IRis Slave Casing (CR2032 Cell).dwg]
2018-06-16 Incorrect Design File Fixed
    [IRis Slave Casing (AA Cell - Bottom Loading).dwg]
2018-07-04 Testing Module Bug Fixes
    [IRis_Master.ino, IRis_Slave.ino, irOps.py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]
2018-07-11 Master Schematic Added
    [IRis - Master Schematic.sch]

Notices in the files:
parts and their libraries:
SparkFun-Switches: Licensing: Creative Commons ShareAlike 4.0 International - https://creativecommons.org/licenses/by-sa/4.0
